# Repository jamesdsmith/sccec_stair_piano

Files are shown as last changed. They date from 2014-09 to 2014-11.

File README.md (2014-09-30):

sccec_stair_piano
=================

Contains all the code and files necessary for the Sierra College Computer Engineering Club's staircase piano project

The project is intended to be installed on a staircase. Laser modules will shoot a laser across the surface of the stairs at a photoresistor, which is hooked into an analog pin on an Arduino. When the person's foot breaks the beam of the laser, the resistance of the photoresistor will decrease and the current to the pin will drop. This will be detected in code, and stored as a state variable on the Arduino.

A Raspberry Pi will communicate with the Arduino over I2C, and will periodically ask the Arduino for the state variable. Reading this state variable will allow the RPi to determine which lasers are blocked, and will play the appropriate sound.

#### Schematic
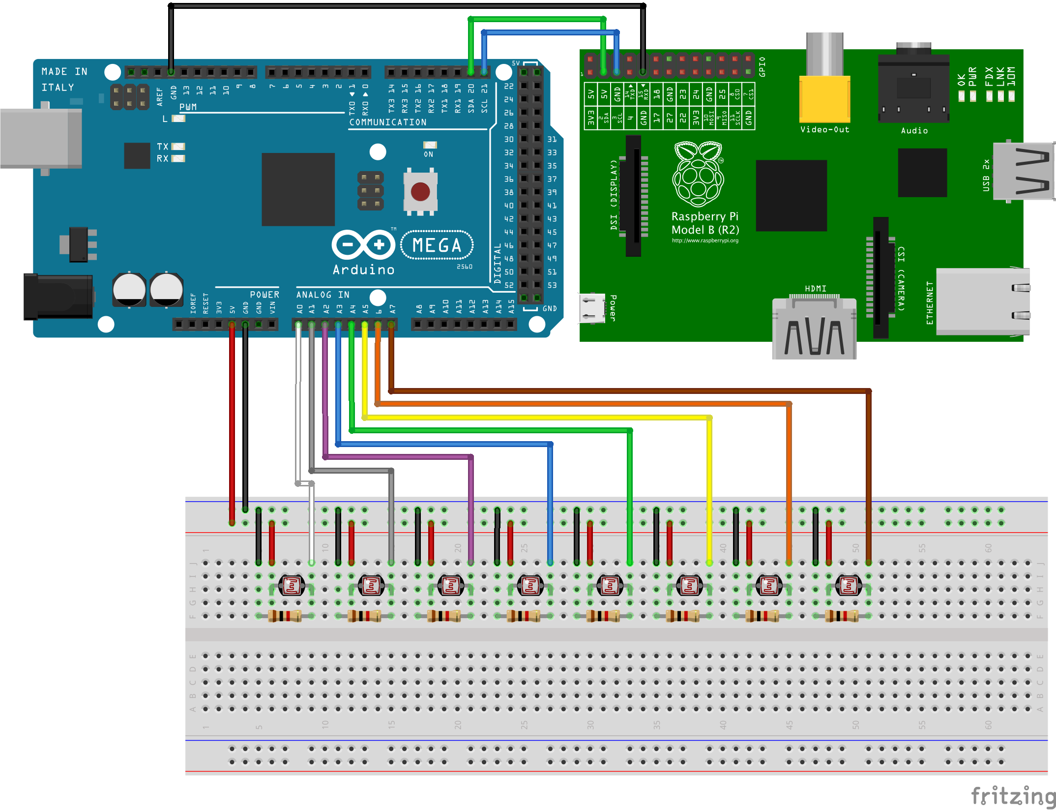
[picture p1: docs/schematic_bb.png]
Stair Piano Schematic


### Requirements:
* Arduino Mega 2560
  * Uno or smaller Arduino usable with 4 or less steps (2 analog pins needed for I2C)
* Raspberry Pi
  * Libraries: SDL, SDL_mixer, i2c-dev
* Components:
  * 8x Photoresistors
  * 8x 1kΩ Resistors
  * 8x 5mW Laser Modules

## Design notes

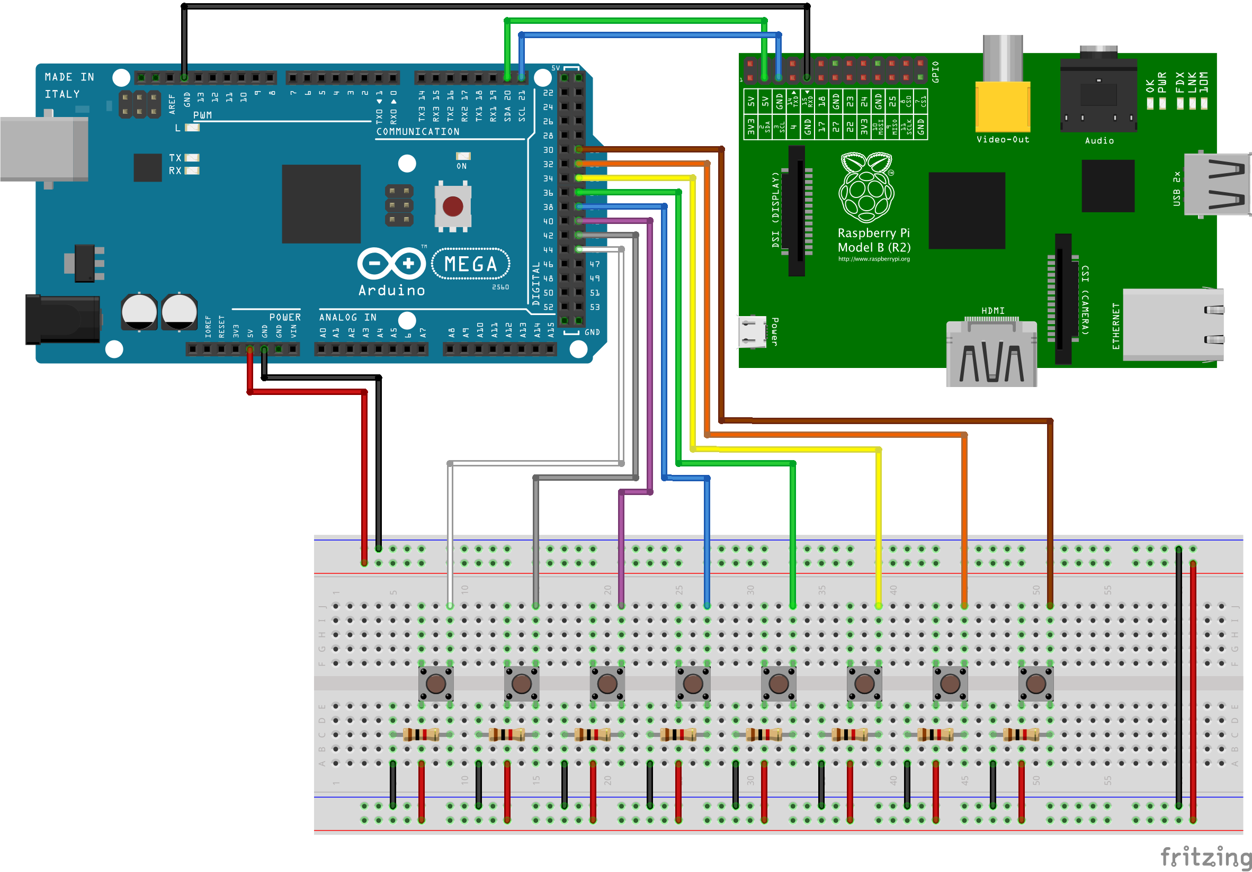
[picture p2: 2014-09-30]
docs/schematic_digital_bb.png

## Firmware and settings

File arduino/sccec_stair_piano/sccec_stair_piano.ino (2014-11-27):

/*
 * Sierra College Computer Engineering Club
 * Staircase Piano Project
 * author: James Smith
 * 
 * This is the Arduino side of the stair project. The Arduino will use the buttonStates
 * library on 8 analog inputs to detect analog button presses (coming from laser pointers
 * pointed at photoresistors) and will keep track of which buttons have been pressed
 * by each setting a bit in a byte. The RPi will request this byte at a specific interval
 * over the I2C connection, and then the Arduino will reset the state and start tracking
 * more button presses.
 *
 * Requires an Arduino Mega, or any Arduino that has at least 10 analog inputs (8 for
 * button presses, 2 for I2C). This project could also be run on an Uno using digital
 * button presses.
 * 
 * TODO: Need to setup button code for all of the analog buttons, just using digital
 * buttons for now as placeholders
 */

#include <Wire.h>

// sets our address for the I2C connection
// The Arduino is setup to be a slave to the RPi
#define SLAVE_ADDRESS 0x04

const int analogPin1 = 0;
const int analogPin2 = 1;
const int analogPin3 = 2;
const int analogPin4 = 3;
const int analogPin5 = 4;
const int analogPin6 = 5;
const int analogPin7 = 6;
const int analogPin8 = 7;

#include "buttonStates.h"
struct buttonState analog1;
struct buttonState analog2;
struct buttonState analog3;
struct buttonState analog4;
struct buttonState analog5;
struct buttonState analog6;
struct buttonState analog7;
struct buttonState analog8;

// each bit in this byte will hold the key state for exactly one button, until that state data
// is transferred to the RPi over I2C
byte keyState = 0;

// analog trigger threshold. This is dependent on the ambient light
int threshold = 700;

#define NOTE_1 0x01
#define NOTE_2 0x02
#define NOTE_3 0x04
#define NOTE_4 0x08
#define NOTE_5 0x10
#define NOTE_6 0x20
#define NOTE_7 0x40
#define NOTE_8 0x80

void setup()
{
  Serial.begin(9600);
  pinMode( analogPin1, INPUT );
  pinMode( analogPin2, INPUT );
  pinMode( analogPin3, INPUT );
  pinMode( analogPin4, INPUT );
  pinMode( analogPin5, INPUT );
  pinMode( analogPin6, INPUT );
  pinMode( analogPin7, INPUT );
  pinMode( analogPin8, INPUT );

  // Setup I2C
  Wire.begin( SLAVE_ADDRESS );
  Wire.onRequest( sendData );
}
int lastState;
void loop()
{
  updateInvAnalogButton( &analog1, analogPin1, threshold );
  updateInvAnalogButton( &analog2, analogPin2, threshold );
  updateInvAnalogButton( &analog3, analogPin3, threshold );
  updateInvAnalogButton( &analog4, analogPin4, threshold );
  updateInvAnalogButton( &analog5, analogPin5, threshold );
  updateInvAnalogButton( &analog6, analogPin6, threshold );
  updateInvAnalogButton( &analog7, analogPin7, threshold );
  updateInvAnalogButton( &analog8, analogPin8, threshold );
  
  if( analog1.Pressed )
  {
    keyState |= NOTE_1;
  }
  if( analog2.Pressed )
  {
    keyState |= NOTE_2;
  }
  if( analog3.Pressed )
  {
    keyState |= NOTE_3;
  }
  if( analog4.Pressed )
  {
    keyState |= NOTE_4;
  }
  if( analog5.Pressed )
  {
    keyState |= NOTE_5;
  }
  if( analog6.Pressed )
  {
    keyState |= NOTE_6;
  }
  if( analog7.Pressed )
  {
    keyState |= NOTE_7;
  }
  if( analog8.Pressed )
  {
    keyState |= NOTE_8;
  }
}

// Send data to the RPi over the Wire protocol (I2C)
void sendData()
{
  Wire.write( keyState );
  keyState = 0;
}

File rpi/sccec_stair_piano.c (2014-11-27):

/*
 * Sierra College Computer Engineering Club
 * Staircase Piano Project
 * author: James Smith
 *
 * This is the Raspberry Pi portion of the piano project, it treats the
 * Arduino as a slave device over I2C and polls the device for its current
 * key state. Each bit of the key state represents one key in the piano.
 * If more keys need to be added we will need to send multiple bytes, so
 * some modifications will need to be made
 *
 * Required libraries: SDL, SDL_mixer, i2c-dev
 */
#include <linux/i2c-dev.h>
#include <stdio.h>
#include <errno.h>
#include <signal.h>
#include <sys/ioctl.h>
#include <fcntl.h>
#include <unistd.h>
#include <stdbool.h>

#include "SDL.h"
#include "SDL_mixer.h"

// defs for SDL Mixer
static const int FREQ = 44100;
static const int FORMAT = MIX_DEFAULT_FORMAT;
static const int CHANNELS = 2;
static const int BUFFER = 2048;

// defs for I2C
#define I2C_ADDRESS 0x04
static const char* DEVICE_NAME = "/dev/i2c-1";
// in micro seconds:
static const int i2c_poll_delay = 10000;

#define SOUNDS 8
Mix_Chunk* sounds[SOUNDS];

bool runProgram = true;

bool initSDL();
void quitSDL();

void handleSigInt( int signum )
{
	// We are only registering SIGINT, so that means close the program
	// with control-c
	runProgram = false;
}

void playSound( int index )
{
	int channel = Mix_PlayChannel( index, sounds[index], 0 );
	if( channel == -1 )
	{
		printf( "Error playing sound: %s\n", Mix_GetError() );
	}
}

int main( int argc, char* args[] )
{
	printf( "Starting sccec_stair_piano...\n" );
	// Initialization
	signal( SIGINT, handleSigInt );

	int i2c;
	if( (i2c = open( DEVICE_NAME, O_RDWR )) < 0 )
	{
		printf( "Error connecting to I2C device: %d\n", DEVICE_NAME );
		exit(1);
	}
	if( ioctl( i2c, I2C_SLAVE, I2C_ADDRESS ) < 0 )
	{
		printf( "Error opening a bus to I2C device\n" );
		exit(1);
	}
	if( !initSDL() )
	{
		printf( "Error initializing SDL\n" );
		exit(1);
	}

	// Load sound files
	sounds[0] = Mix_LoadWAV( "/home/pi/Projects/sccec_stair_piano/sounds/C2.wav" );
	sounds[1] = Mix_LoadWAV( "/home/pi/Projects/sccec_stair_piano/sounds/D2.wav" );
	sounds[2] = Mix_LoadWAV( "/home/pi/Projects/sccec_stair_piano/sounds/E2.wav" );
	sounds[3] = Mix_LoadWAV( "/home/pi/Projects/sccec_stair_piano/sounds/F2.wav" );
	sounds[4] = Mix_LoadWAV( "/home/pi/Projects/sccec_stair_piano/sounds/G2.wav" );
	sounds[5] = Mix_LoadWAV( "/home/pi/Projects/sccec_stair_piano/sounds/A2.wav" );
	sounds[6] = Mix_LoadWAV( "/home/pi/Projects/sccec_stair_piano/sounds/B2.wav" );
	sounds[7] = Mix_LoadWAV( "/home/pi/Projects/sccec_stair_piano/sounds/C3.wav" );

	for( int i = 0; i < SOUNDS; ++i )
	{
		if( !sounds[i] )
		{
			printf( "Error loading sound file %d: %s\n", i, Mix_GetError() );
		}
	}

	// Play a sound to signal that the program has started
	// mostly useful when running this program on boot
	playSound( 0 );

	// Holds the data we read from the arduino over I2C
	unsigned char data[1];

	// Loop until we recieve a SIGINT
	while( runProgram )
	{
		if( read( i2c, data, 1 ) == 1 )
		{
			char state = data[0];
			if( state != 0 )
			{
				//printf( "%d\n", state );
			}
			for( int i = 0; i < 8; ++i )
			{
				if( state & 0x01 )
				{
					playSound( i );
				}
				state = state >> 1;
			}
		}
		usleep( i2c_poll_delay );
	}

	// Cleanup time
	close( i2c );
	for( int i = 0; i < SOUNDS; ++i )
	{
		if( sounds[i] )
		{
			Mix_FreeChunk( sounds[i] );
		}
	}

	quitSDL();
	return 0;
}

bool initSDL()
{
        if( SDL_Init( SDL_INIT_AUDIO ) == -1 )
        {
                printf( "Init Error: %s\n", SDL_GetError() );
                return false;
        }
        int initFlags = MIX_INIT_MP3;
        int flags = Mix_Init( initFlags );
        if( initFlags & flags != flags )
        {
                printf( "Error initializing file types: %s\n", Mix_GetError() );
        }

        if( Mix_OpenAudio( FREQ, FORMAT, CHANNELS, BUFFER ) == -1 )
        {
                printf( "Init Audio Error: %s\n", Mix_GetError() );
                return false;
        }
        Mix_AllocateChannels( 16 );
	return true;
}

void quitSDL()
{
	Mix_CloseAudio();
	Mix_Quit();
	SDL_Quit();
}

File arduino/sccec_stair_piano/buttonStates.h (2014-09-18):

#ifndef _BUTTONSTATES_H_
#define _BUTTONSTATES_H_

/*
 * ButtonState Library
 * 
 * author: James Smith, codefiend@gmail.com
 * 
 * description: This library contains a very simple state machine to be used with button-like
 *              inputs for Arduino projects.
 * 
 * usage: Declare a buttonState structure in your code and pass it to the desired update
 *        function. Digital reads from digital pins, Analog reads from analog pins. The Inv
 *        functions have an inverted effect (Pressed happens when pin state = LOW). Analog
 *        requires a trigger threshold, when the analogPin reads above this trigger level,
 *        the button will trigger.
 * 
 *        updateDigitalButton    - Digital input activated when closing a circuit
 *        updateInvDigitalButton - Digital input activated when opening a circuit
 *        updateAnalogButton     - Analog input activated when analog source >= threshold
 *        updateInvAnalogButton  - Analog input activated when analog source <= threshold
 * 
 *        All functions take the address of a buttonState structure as their first argument,
 *        and a pin to test as their second argument. The analog functions take a threshold
 *        as their third argument.
 * 
 * example:
 *   #include "buttonStates.h"
 *   int buttonPin = 2;
 *   struct buttonState button;
 * 
 *   void setup()
 *   {
 *     pinMode( buttonPin, INPUT );
 *   }
 * 
 *   void loop()
 *   {
 *     updateDigitalButton( &button, buttonPin );
 *     if( button.Pressed )
 *     {
 *       ...
 *     }
 *   }
 */

/* Buttons will be locked out from triggering for this many milliseconds after a trigger */
const unsigned long bounceLock = 100;

typedef struct buttonState
{
  bool Pressed;
  bool Held;
  unsigned long lastTime;
};

void updateDigitalButton( struct buttonState* state, int buttonPin )
{
  int pinState = digitalRead( buttonPin );
  if( state->Pressed == false && state->Held == false && pinState == HIGH && (millis() - state->lastTime) > bounceLock  )
  {
    state->Pressed = true;
    state->lastTime = millis();
  }
  else if( state->Pressed == true && state->Held == false && pinState == HIGH )
  {
    state->Pressed = false;
    state->Held = true;
  }
  else if( pinState == LOW )
  {
    state->Pressed = false;
    state->Held = false;
  }
}

void updateInvDigitalButton( struct buttonState* state, int buttonPin )
{
  int pinState = digitalRead( buttonPin );
  if( state->Pressed == false && state->Held == false && pinState == LOW && (millis() - state->lastTime) > bounceLock )
  {
    state->Pressed = true;
  }
  else if( state->Pressed == true && state->Held == false && pinState == LOW )
  {
    state->Pressed = false;
    state->Held = true;
  }
  else if( pinState == HIGH )
  {
    state->Pressed = false;
    state->Held = false;
  }
}

void updateAnalogButton( struct buttonState* state, int buttonPin, int threshold )
{
  int pinState = analogRead( buttonPin );
  if( state->Pressed == false && state->Held == false && pinState >= threshold && (millis() - state->lastTime) > bounceLock )
  {
    state->Pressed = true;
  }
  else if( state->Pressed == true && state->Held == false && pinState >= threshold )
  {
    state->Pressed = false;
    state->Held = true;
  }
  else if( pinState < threshold )
  {
    state->Pressed = false;
    state->Held = false;
  }
}

void updateInvAnalogButton( struct buttonState* state, int buttonPin, int threshold )
{
  int pinState = analogRead( buttonPin );
  if( state->Pressed == false && state->Held == false && pinState <= threshold && (millis() - state->lastTime) > bounceLock )
  {
    state->Pressed = true;
  }
  else if( state->Pressed == true && state->Held == false && pinState <= threshold )
  {
    state->Pressed = false;
    state->Held = true;
  }
  else if( pinState > threshold )
  {
    state->Pressed = false;
    state->Held = false;
  }
}

#endif

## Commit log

2014-09-01 Added an example code snippet to better illustrate buttonState usage
2014-09-01 Added more clarifying comments to the header for buttonStates.h
2014-09-13 Added bounce lockout to buttonStates library
2014-09-18 removed some serial prints. increased bounce lock timer
2014-09-18 Temporary reverting changes to sccec_stair_piano.ino for sending to remote
    [sccec_stair_piano.ino]
2014-09-21 setting up the arduino code to use I2C, also adding some placeholder code for when it comes time to add more buttons
2014-09-21 Removing old unused header files used to play sounds on the Arduino DAC
2014-09-21 Adding arduino subdirectory This is an attempt at directory management, so when I add the raspberry pi code, it can be organized. An annoying quirk about this, the Arduino IDE doesnt like it when the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
    [buttonStates.h, sccec_stair_piano.ino]
2014-09-21 Adding Raspberry Pi portion of the project The raspberry pi code polls the arduino as an I2C device, and retrieves a key state which determines the sounds to play
2014-09-21 Updated some of the error messages Changed the location of where it searches for sound files. Should probably consider making this a relative path asap
    [sccec_stair_piano.cpp]
2014-09-21 Raspberry Pi: C compliance, updated build There was no need for the RPi code to be in C++ since it didn't use any C++ features Checking in the binary in case anyone wants to run the project on their 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
    [sccec_stair_piano.c]
2014-09-22 Adding analog button placeholders All of the analog related code should be uncommented for the final build. Leaving it commented out because I dont want the analog pins to trigger based on anything r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
2014-09-30 Adding schematics
    [schematic.fzz, schematic_digital.fzz]
2014-09-30 Adding schematic to the readme
2014-11-27 Adding final pin configurations
